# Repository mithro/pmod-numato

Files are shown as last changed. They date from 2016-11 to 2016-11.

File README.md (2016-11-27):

# pmod-numato

This adapter is useful for the following;

 * Adapting the "XADC" style to the "HS" style.
    - See [my high speed Pmod sheet for details](https://docs.google.com/spreadsheets/d/1D-GboyrP57VVpejQzEm0P1WEORo1LAIt92hk1bZGEoo/edit#gid=725118408).

 * From from Numato's spacing (0.3145 inch, pin to pin) to
   Digilent's spacing (0.3 inch, edge to edge).

The traces in a diff pair have been length and skewed matched with a tolerance
of ~1 mil.

The diff pairs as a group have been length matched to 0.8537 inches (21.6mm)
long with a tolerance of 20 mil (0.5mm).

To use Numato spacing device on Digilent host;
 * B side should be up.
 * The XHS side should be loaded with pins.
 * The XADC side should be loaded with socket.

To use Digilent spacing device on Numato host;
 * A side should be up.
 * The XHS side should be loaded with socket.
 * The XADC side should be loaded with pins.

# Board Manufacturing

 *  5mil (0.127mm) trace width
 *  5mil (0.127mm) trace clearance

 * 12 mil (0.3048mm) drill size
 *  6 mil (0.1524mm) annular ring
 * 24 mil (0.6096mm) via size (6mil+12mil+6mil)

 *  6 mil (0.1524) silkscreen width

This can be meet by;
 * [Hackvana by requesting the 5mil option](https://docs.google.com/document/d/1p6FH25ltGpzJQ5_8fbflDukqEKghiEcpuhJpngth2Is/edit)
 * [OHS Park's Four Layer Boards](http://docs.oshpark.com/services/)

## License

The board is licensed under a
Creative Commons Attribution-ShareAlike 4.0 International License.

You should have received a copy of the license along with this
work.  If not, see <http://creativecommons.org/licenses/by-sa/4.0/>.



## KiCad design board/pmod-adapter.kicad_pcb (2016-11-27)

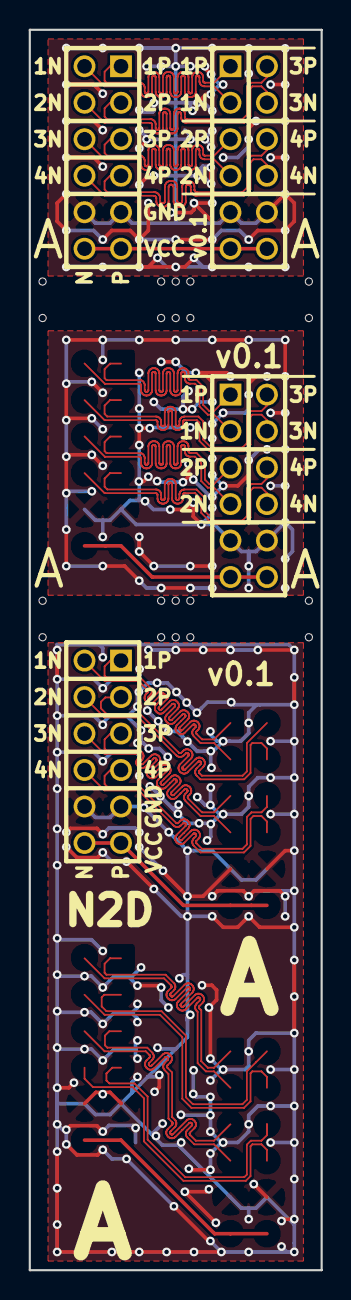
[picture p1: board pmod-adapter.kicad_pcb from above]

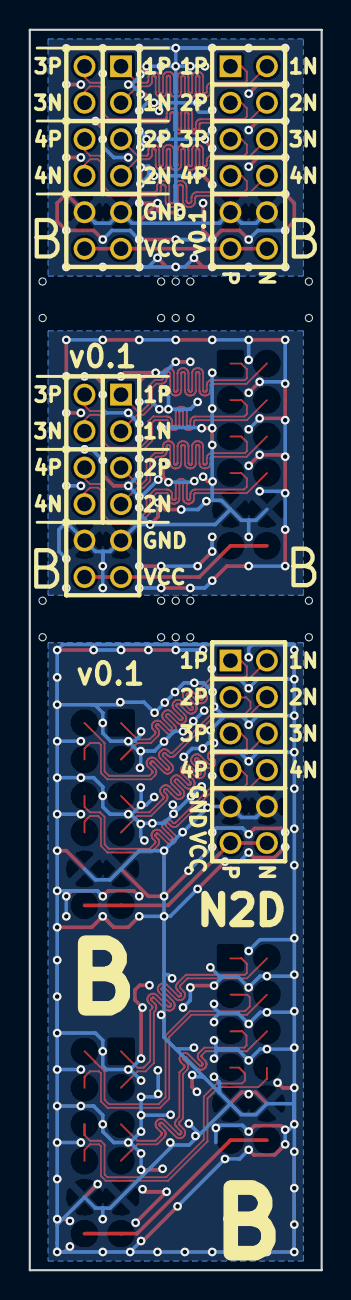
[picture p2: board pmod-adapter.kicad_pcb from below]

Board: 2 copper layers, 20.3 x 86.4 mm, 4 parts (2 on the bottom side), 13 nets.

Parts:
PH1, PH2: PMOD-Device-x2-Type-XHS; pmod_pin_array_6x2_hs
PX1, PX3: PMOD-Device-x2-Type-XADC; pmod_pin_array_6x2_xadc

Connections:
/GND2: PX1.5, PX1.11
/GND34: PH1.5, PH1.11, PH2.5, PH2.11, PX3.5, PX3.11
/J4A_N: PH1.2, PX3.7
/J4A_P: PH1.1, PX3.1
/J4B_N: PH1.8, PX3.8
/J4B_P: PH1.7, PX3.2
/J4C_N: PH1.4, PX3.9
/J4C_P: PH1.3, PX3.3
/J4D_N: PH1.10, PX3.10
/J4D_P: PH1.9, PX3.4
/VCC2: PX1.6, PX1.12
/VCC3: PH2.6, PH2.12
/VCC4: PH1.6, PH1.12, PX3.6, PX3.12

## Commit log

2016-11-15 Adding another dimension.
    [pmod-adapter.kicad_pcb]
2016-11-15 Increasing to 4 headers.
    [pmod-adapter.sch]
2016-11-19 Split the GND net for each part.
    [pmod-adapter.sch]
2016-11-19 Updating PCB.
    [pmod-adapter.kicad_pcb]
2016-11-19 Lots of updates.
    [pmod-adapter.kicad_pcb, pmod-adapter.sch]
2016-11-19 Small updates.
    [pmod-adapter.kicad_pcb]
2016-11-19 Working on getting the Numato spacing right.
    [pmod-adapter.kicad_pcb]
2016-11-19 Updating comments a little.
    [pmod-adapter.kicad_pcb, pmod-adapter.sch]
2016-11-20 Rework the schematic to make board easier to route.
    [pmod-adapter.kicad_pcb, pmod-adapter.sch]
2016-11-20 Routing all pairs.
    [pmod-adapter.kicad_pcb, pmod-adapter.sch]
2016-11-20 Committing before doing length tunning.
    [pmod-adapter.kicad_pcb]
2016-11-20 Length matching.
    [pmod-adapter.kicad_pcb]
2016-11-20 Adding tie vias
    [pmod-adapter.kicad_pcb, pmod-adapter.sch]
2016-11-20 Adding board details.
2016-11-20 Working on the cuts and pours.
    [pmod-adapter.kicad_pcb]
2016-11-20 Remove extra silkscreen object.
    [pmod-adapter.kicad_pcb]
2016-11-26 Adding more gnd vias
    [pmod-adapter.kicad_pcb]
2016-11-26 Temp commit.
    [pmod-adapter.kicad_pcb]
2016-11-26 Slowly adding more vias.
    [pmod-adapter.kicad_pcb]
2016-11-26 One more via.
    [pmod-adapter.kicad_pcb]
2016-11-26 Move the text around slightly.
    [pmod-adapter.kicad_pcb]
2016-11-26 Slight silkscreen fixes.
    [pmod-adapter.kicad_pcb]
2016-11-26 Making the text thicker.
    [pmod-adapter.kicad_pcb]
2016-11-26 Small alignment fix.
    [pmod-adapter.kicad_pcb]
2016-11-26 Fixing the B on the silkscreen.
    [pmod-adapter.kicad_pcb]
2016-11-27 Fixing small variance.
    [pmod-adapter.kicad_pcb]
2016-11-27 Fixing the diffpair documentation.
    [pmod-adapter.kicad_pcb]
2016-11-27 Bumping version to v0.1
    [pmod-adapter-CuBottom.gbl, pmod-adapter-CuTop.gtl, pmod-adapter-EdgeCuts.gm1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]
